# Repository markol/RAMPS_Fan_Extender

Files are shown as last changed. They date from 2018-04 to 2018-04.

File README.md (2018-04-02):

 
##Fan extension board for RAMPS##
This extension allows you to connect additional 4 fans into RAMPS board (plugged into servo pins). Board is single sided and was designed for home etching, uses THT and SMD soldering components. Make sure board dimensions (16x40mm) are not colliding with your actual setup. NPN transistors can be used as well instead of FET's. Voltage above 5V is provided by additional connector plug, reversed polarity may destory electronics.
Configuration process is similar to other boards, example [here](https://www.geeetech.com/wiki/index.php/Reprap_Ramps1.4_RRD_Fan_Extender), use pins 11, 6, 5 or 4. Made with KiCAD.
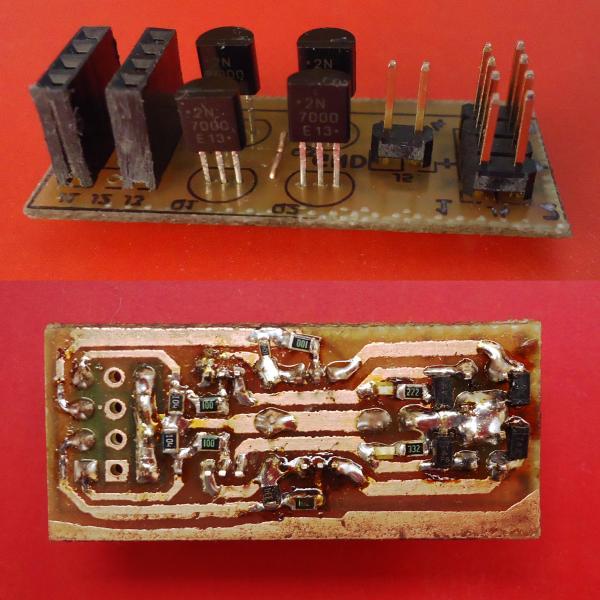
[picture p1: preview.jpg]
Prewiev


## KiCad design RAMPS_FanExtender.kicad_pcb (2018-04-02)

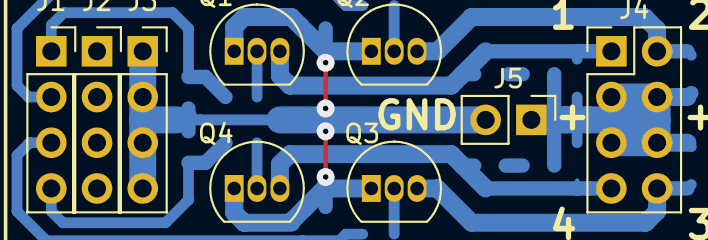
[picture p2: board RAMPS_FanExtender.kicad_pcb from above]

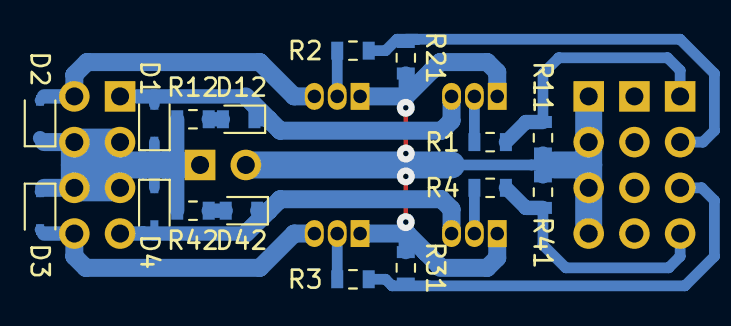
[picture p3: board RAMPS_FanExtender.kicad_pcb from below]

Board: 2 copper layers, 25 parts (16 on the bottom side), 16 nets.

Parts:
D1, D2, D3, D4: 1N4148WS; D_SOD-323
D12, D42: LED; LED_0603_1608Metric
J1: Conn_01; PinSocket_1x04_P2.54mm_Vertical
J2: Conn_02; PinSocket_1x04_P2.54mm_Vertical
J3: Conn_03; PinSocket_1x04_P2.54mm_Vertical
J4: Conn_FANS; PinHeader_2x04_P2.54mm_Vertical
J5: Conn_01x02; PinHeader_1x02_P2.54mm_Vertical
Q1, Q2, Q3, Q4: 2N7000; TO-92_Inline
R1, R2, R3, R4: 10R; R_0603_1608Metric
R11, R21, R31, R41: 100K; R_0603_1608Metric
R12, R42: 2K; R_0603_1608Metric

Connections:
+12V: D1.1, D2.1, D3.1, D4.1, J4.3, J4.4, J4.5, J4.6, J5.1, R12.2, R42.2
/FAN1_OUT: D1.2, D12.1, J4.1, Q1.3
/FAN1_PWM: J1.1, R1.2, R11.2
/FAN2_OUT: D2.2, J4.2, Q2.3
/FAN2_PWM: J1.2, R2.1, R21.1
/FAN3_OUT: D3.2, J4.8, Q3.3
/FAN3_PWM: J1.3, R3.2, R31.2
/FAN4_OUT: D4.2, D42.1, J4.7, Q4.3
/FAN4_PWM: J1.4, R4.1, R41.1
GND: J3.1, J3.2, J3.3, J3.4, J5.2, Q1.1, Q2.1, Q3.1, Q4.1, R11.1, R21.2, R31.1, R41.2
unnamed: D12.2, R12.1
unnamed: D42.2, R42.1
unnamed: Q1.2, R1.1
unnamed: Q2.2, R2.2
unnamed: Q3.2, R3.1
unnamed: Q4.2, R4.2
